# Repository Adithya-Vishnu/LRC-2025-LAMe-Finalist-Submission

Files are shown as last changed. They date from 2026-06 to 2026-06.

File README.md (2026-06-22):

# LRC-2025-LAMe-Finalist-Submission
Multi-robot coordination system developed for the Lam Research Challenge 2025, featuring an autonomous line follower (ALFR), a mecanum-based robotic manipulator (SARM), arena automation, and parametric CAD design.

# LAMe Multi-Robot Coordination System

### Lam Research Challenge 2025 | Top 24 Finalist Team

A cooperative multi-robot system developed for the **Lam Research Challenge 2025 (LRC)** by **Team LAMe**, comprising an autonomous line-following robot (**ALFR**) and a manually operated robotic manipulator (**SARM**) working together to complete a dynamic obstacle-clearing and navigation challenge.

Our team advanced from a pool of **7000+ applicants** to become one of the **Top 24 teams nationally**, qualifying for the final round held in Bangalore.

---

## Team LAMe

* Adithya Vishnu
* Harsh Chandwani
* Sreeja Srinivasan
* Sparsh Pradeep Jain

---

## Project Overview

The challenge required the development of two robots capable of coordinated task execution:

### ALFR (Advanced Line Follower Robot)

An autonomous robot responsible for:

* Following a predefined arena path
* Detecting and responding to obstacles
* Triggering arena events through gate interactions
* Completing navigation tasks within strict timing constraints

### SARM (Single Arm Moving Robot)

A mecanum-wheel-based robotic manipulator responsible for:

* Omnidirectional movement
* Identifying and removing obstacles
* Pick-and-place operations
* Clearing the path for ALFR navigation

The robots operate together, with SARM removing obstacles while ALFR autonomously continues task execution once the route is cleared.

---

## Key Features

### Autonomous Navigation

* PID-based line following
* Multi-sensor line detection
* Obstacle-aware navigation
* Recovery logic for line loss
* Real-time path correction

### Robotic Manipulation

* Mobile robotic arm platform
* Mecanum wheel omnidirectional drive
* Object grasping and relocation
* Pick-and-place workflow
* Manual control interface

### Arena Automation

* Gate-triggered events
* Relay-based control systems
* Automated LED activation
* Fluid delivery sequence integration
* Event-driven challenge execution

### Mechanical Design

* Custom-designed ALFR chassis
* Custom SARM mechanical components
* Arena infrastructure design
* 3D-printed robot components
* Mechanical integration and assembly

### CAD Automation

* Fully parametric flange-bolt assembly
* Excel-linked SolidWorks design tables
* Equation-driven geometry generation
* Automated design regeneration
* Scalable assembly configuration

---

## Software Stack

### Simulation

* CoppeliaSim

### Programming

* Arduino
* C++
* Python

### CAD

* SolidWorks
* Fusion 360

### Electronics

* ESP32
* IR Sensor Arrays
* Ultrasonic Sensors
* Relay Modules
* Load Cells
* Peristaltic Pump Systems

---

## Competition Workflow

1. ALFR begins autonomous navigation.
2. Obstacles encountered on the route halt progression.
3. SARM identifies and removes obstacles.
4. ALFR resumes navigation.
5. Gate-based events trigger arena automation.
6. Fluid delivery and LED activation tasks are executed.
7. ALFR completes the course and reaches the final checkpoint.

---

## Results

* Qualified among **Top 96** from over **7000 applicants**
* Advanced to the **Top 24 Finalists Nationwide**
* Invited to compete at the **Lam Research Challenge Finals, Bangalore**
* Successfully completed both simulation and hardware evaluation rounds

---

## Repository Structure

```text
├── CAD/
├── CoppeliaSim/
├── Arduino/
├── Documentation/
├── Hardware/
├── Images/
├── Videos/
└── README.md
```

---

## Future Improvements

* ROS2 integration
* Autonomous obstacle removal
* Computer vision-based object detection
* SLAM-assisted navigation
* Multi-agent task planning
* Wireless telemetry dashboard

---

## Acknowledgements

We thank Lam Research, T-Works, IIT Kanpur, and the Robotics Club community for providing the opportunity, resources, and mentorship that made this project possible.

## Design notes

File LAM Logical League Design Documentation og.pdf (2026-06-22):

# LAM Research Challenge 2025

# Stage-1: Logical League

## Team LAMe: LRC-U-0517-1

## Members:

### Adithya Vishnu

### Harsh Chandwani

### Sreeja Srinivasan

### Sparsh Pradeep Jain

# Key challenges handled

- Obstacle Configuration

To evaluate the system’s obstacle detection and navigation capabilities, three distinct obstacles were strategically positioned within the arena to introduce varying levels of difficulty.

- Obstacle 1: Placed along a straight path, designed to test basic obstacle detection and removal efficiency.
- Obstacle 2: Located on a corner, introducing a moderate challenge due to limited maneuvering space.
- Obstacle 3: Positioned immediately after a turn, simulating a complex real-world obstruction scenario that required precise timing and coordination between the SRM and ALFR.

This configuration ensured a progressive difficulty setup, allowing systematic testing of both detection accuracy and response timing during obstacle clearance.

- Obstacle Interaction Logic

The obstacle interaction mechanism involved two coordinated systems — the Support Robot Module (SRM) and the Autonomous Line-Following Robot (ALFR).

- The SRM was responsible for picking up, and relocating obstacles away from the line path to maintain a clear route for the ALFR.
- The ALFR was programmed to stop automatically upon detecting an obstacle and resume navigation only after the SRM had successfully cleared it.

During testing, three different obstacle shapes — a cube, a cylinder, and a sphere — were used. The SRM’s gripper arm was able successfully lift each shape, demonstrating versatility and precision in obstacle handling.

- Time Limit

The arena challenge included a time-based performance metric, requiring the task to be completed within 10 minutes.

- In the baseline test (without obstacles), the ALFR successfully navigated the entire arena in 40 seconds, showcasing efficient line-following and path optimization.
- In the full test (with all obstacles present), the combined system of SRM and ALFR completed the entire course in 3 minutes, clearing each obstacle sequentially as encountered.

This performance demonstrated reliable coordination between the robots and efficient task execution well within the prescribed time limit.

- Peristaltic Pump Verification

We have used a load cell to measure the weight of water dispensed and all other components of the circuits will be tuned such that it triggers the switch at the exact weight required.

# Circuit Diagram:

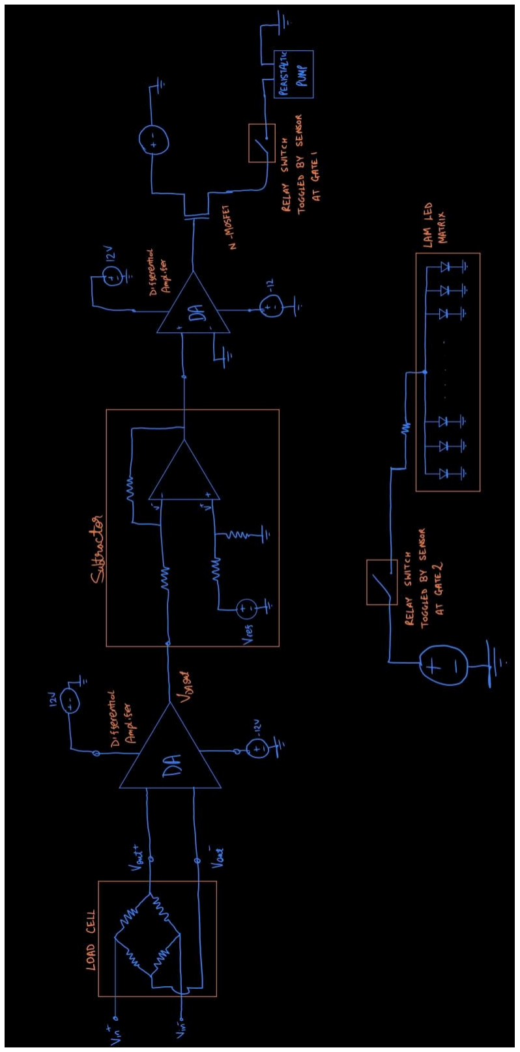
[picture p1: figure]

## Detailed Explanation:

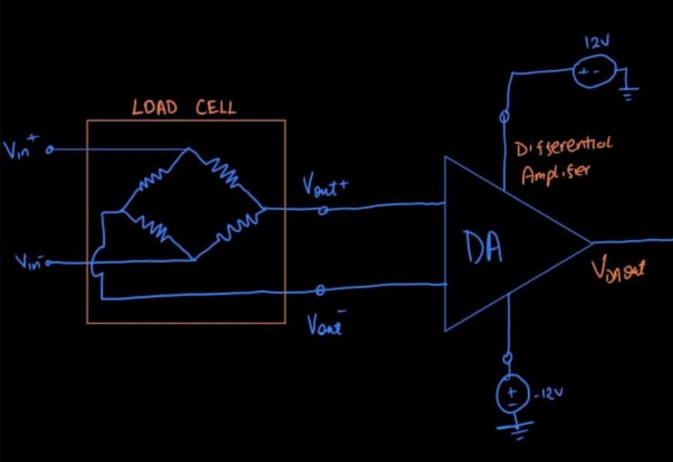
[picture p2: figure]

A load cell is a transducer that converts mechanical force (weight or load) into an electrical signal. It operates based on the strain gauge principle, where a change in force causes a corresponding change in electrical resistance.

When weight is applied to the load cell, the metal body (elastic element) deforms slightly. This deformation alters the resistance of the strain gauges attached to it, which are connected in a Wheatstone bridge configuration. The resulting output is a small differential voltage proportional to the applied load.

Since this voltage is typically in the millivolt range (mV), it must be amplified using an instrumentation amplifier such as the HX711 module.

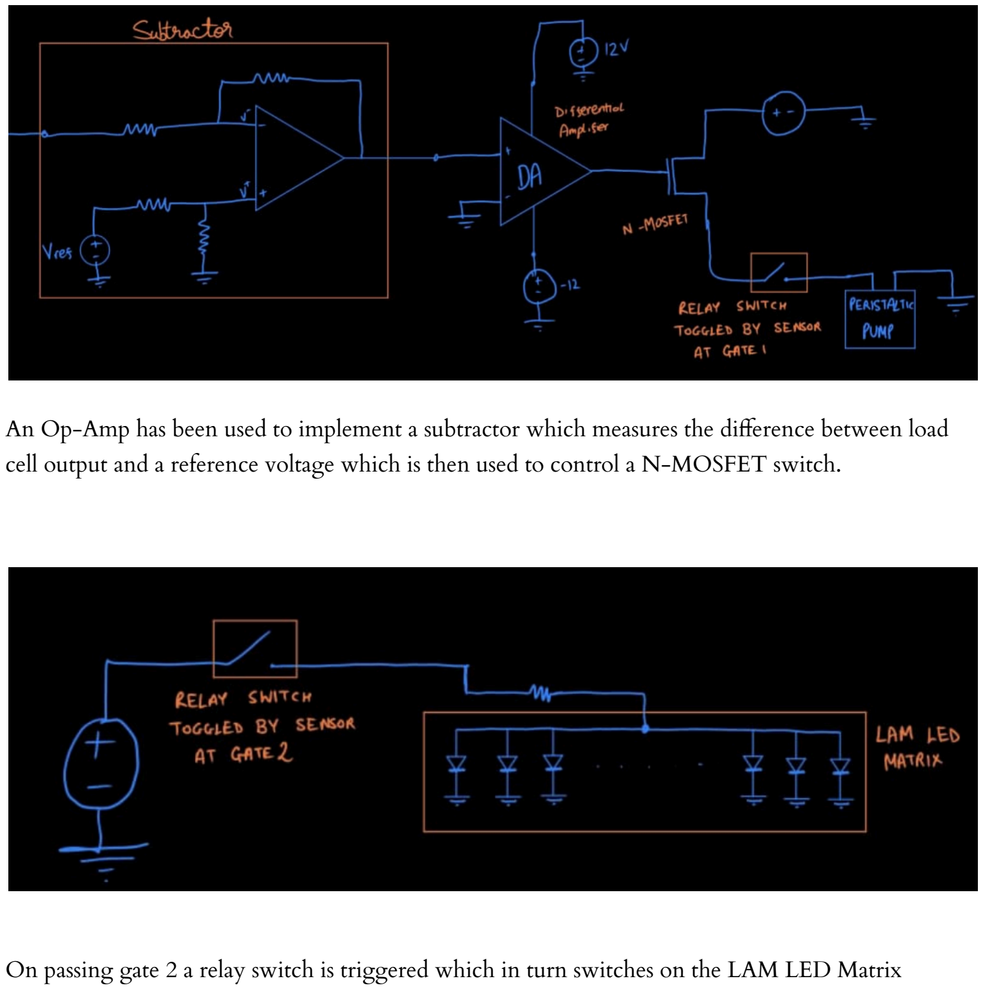
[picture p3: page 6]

An Op-Amp has been used to implement a subtractor which measures the difference between load cell output and a reference voltage which is then used to control a N-MOSFET switch.

On passing gate 2 a relay switch is triggered which in turn switches on the LAM LED Matrix

# Key features of custom code for line following of ALFR:

### 1. Error Calculation with 5 IR sensors:

The five IR sensors return intensity values (black < 0.5).
Each sensor is assigned a weight (−4000 to +4000) based on its position.
The error is the weighted average of all active (black-detecting) sensors:

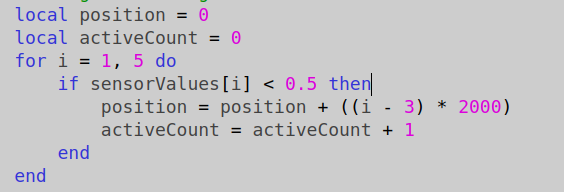
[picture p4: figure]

### 2. PID Control:

Computes proportional, integral, and derivative terms of the error to correct steering smoothly. The PID parameters were carefully tuned to achieve maximum speed and accuracy in line tracking.

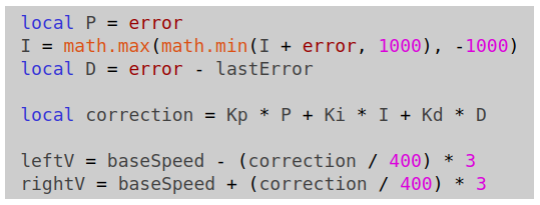
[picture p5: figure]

### 3. Obstacle Handling:

Stops the robot when the proximity sensor detects an obstacle.

### 4. Line Recovery:

If all sensors lose the line, the robot turns in the direction of the last known error until the line is found again.

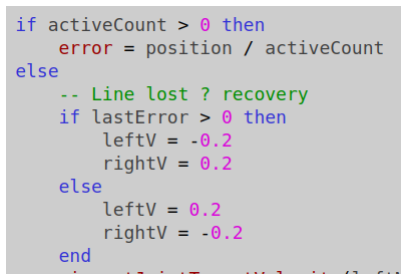
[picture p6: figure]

Key features of custom code for manual control of Single Arm Robot:

### 1. Custom Graphical UI:

Creates an on-screen control panel using simUI.create() with buttons for forward, backward, left, right, rotation, stop, and pick operations.

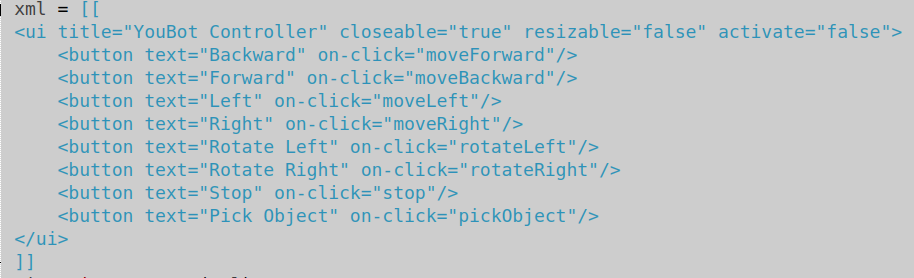
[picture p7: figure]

### 2. Mecanum Wheel Drive System:

Uses mecanum wheels to achieve omnidirectional movement, allowing the robot to move forward, backward, sideways, and rotate in place.

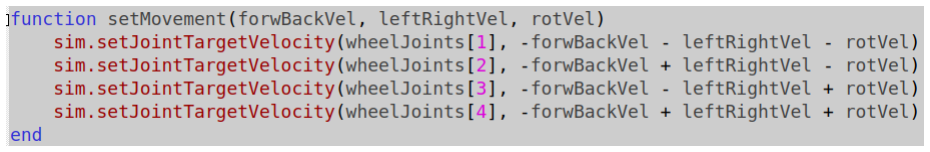
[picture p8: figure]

### 3. Arm and Gripper Control:

Functions to position the robotic arm and open/close the gripper using joint target positions.

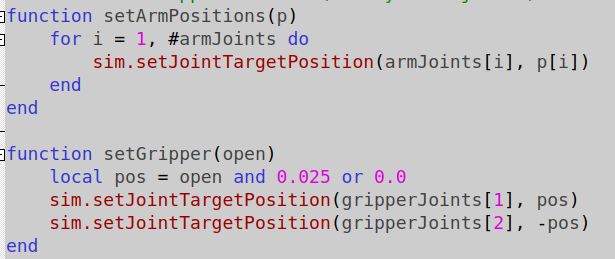
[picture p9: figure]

### 4. Pick-and-Place Operation:

Automated routine configured to pick an object: move to a ready pose, lower arm, close gripper, attach object, and lift it.

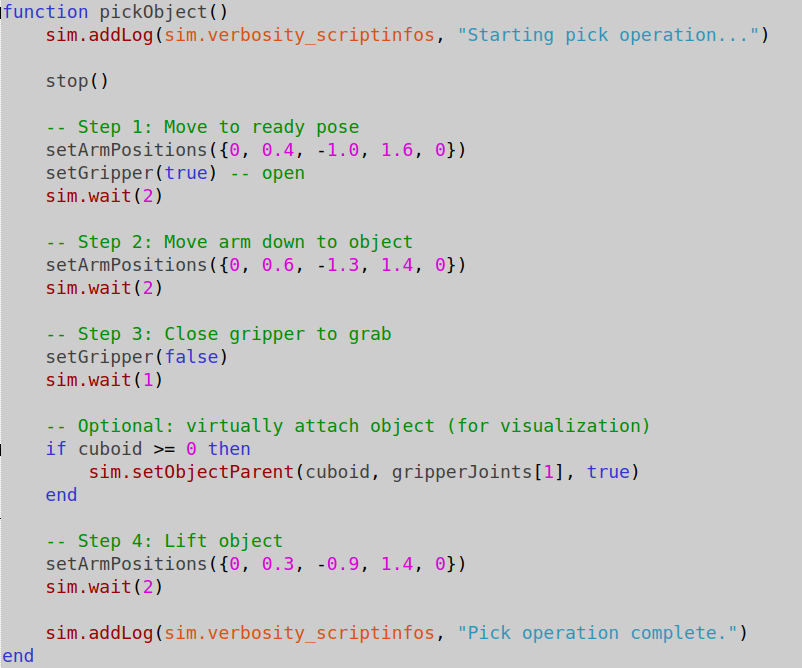
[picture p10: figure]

## Key features of code for LAM LED turning on when ALFR passes through gate 2:

### 1. LED color control

Turns LEDs red when activated, and black otherwise.

### 2. Persistent state flag

Keeps LEDs on once triggered, even after the object moves away.

# CUSTOM MODELS

## ALFR:

## So coming to the model of Automatic

Line follower Robot,

## we chose to go with this design because it has rotational symmetry, less moment of inertia to reduce

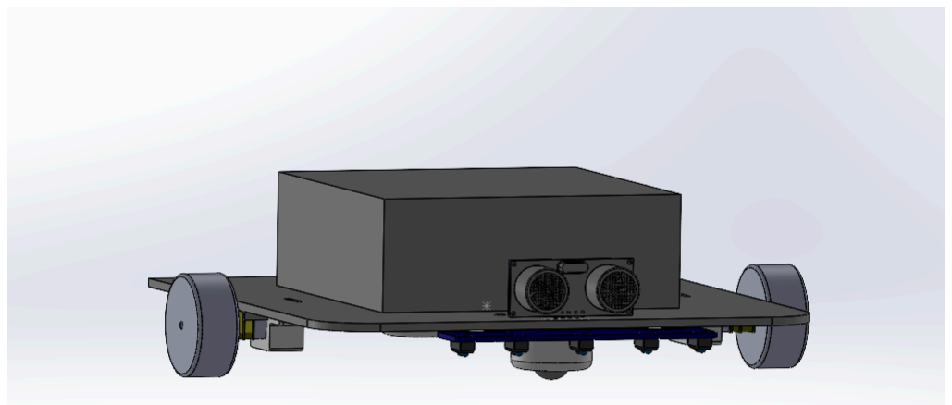
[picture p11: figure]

## chances of overshooting, which is really important for most efficient path following and preventing repetitive errors. And to remove any chance of rotation asymmetry we have provided two caster wheels at the front and

the back, to remove any chance of uneven torque distribution.

## Other than that we have made the design such that there is no chance of toppling and the mass is centred since the battery and other electronic

components are kept at the centre.

## SINGLE ARM - ROBOT

So the bot consists of multiple links. It starts from a stationary base that is attached to the mechanum wheel base. Then the rotating body is attached onto this stationary base through a servo and ball bearing for additional support. Now the first extension and second extension are designed to be of minimal weight and have enough supports (additional triangulations have been provided for this purpose to reduce the material used.)

### Now coming to the gripper, we have made the gripper such that it is adjustable for

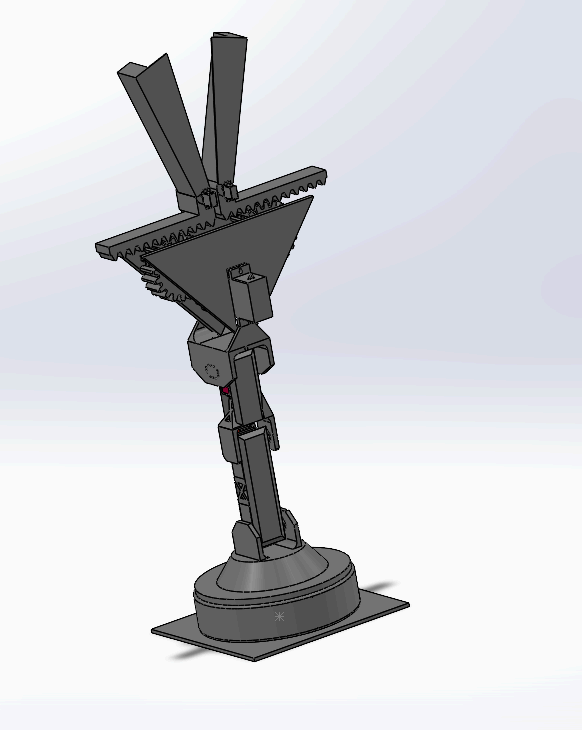
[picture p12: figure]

varying sizes and shapes of objects. This uses the principle of rack and pinion gears and a set of three intersecting spur gears to transfer the torque from one servo motor to both the set of racks equally thereby expanding the distance between the two arms. Then the design includes two additional servos on each

rack to better adjust the arms to fit regardless of what shape the object is of.

# PERISTALTIC PUMP

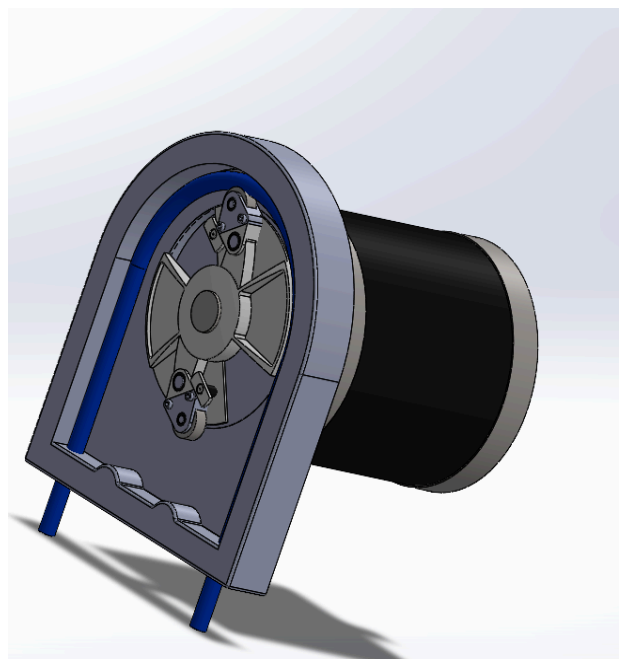
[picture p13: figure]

## Coming to the basic design of the peristaltic pump, We have used two rollers connected to a motor, that revolves the rollers periodically and controlled, which pushes specific volumes of fluid through the tube that can be controlled by controlling the number of rotations and changing

the thickness of the tube.

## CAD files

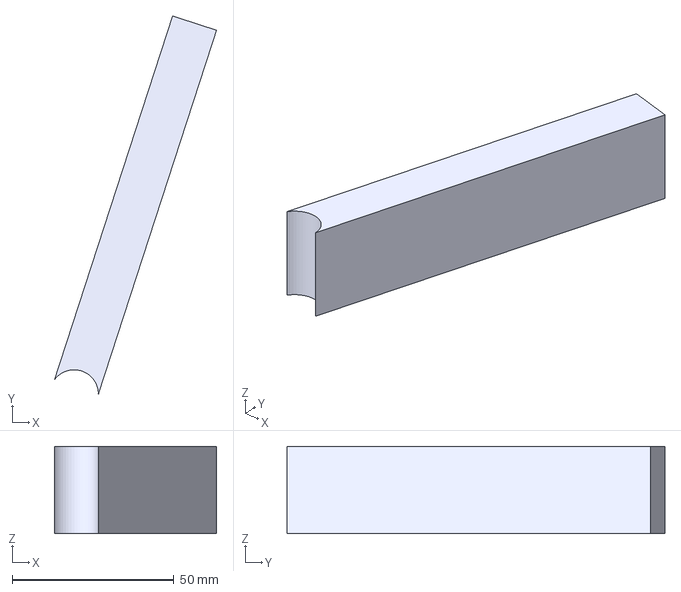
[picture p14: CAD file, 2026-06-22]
CAD/rack2_leg.step
50.0 x 116.7 x 27.0 mm

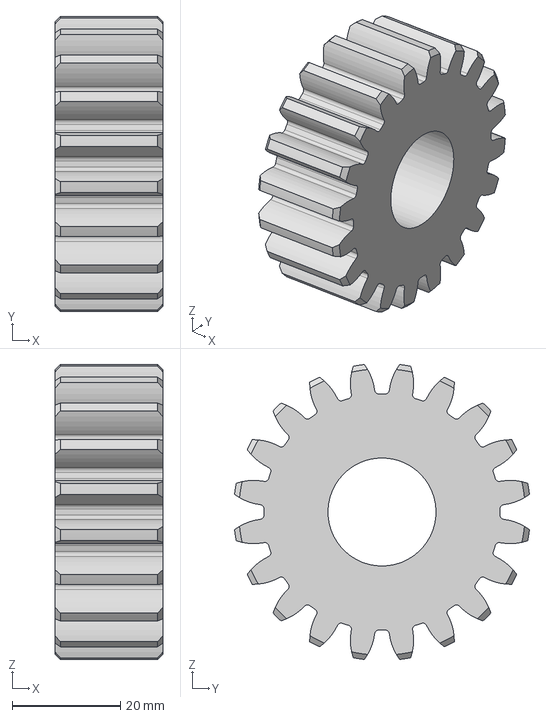
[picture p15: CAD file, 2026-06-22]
CAD/spur gear 20 teeth and 2.5mm module v1.step
20.0 x 54.6 x 54.6 mm

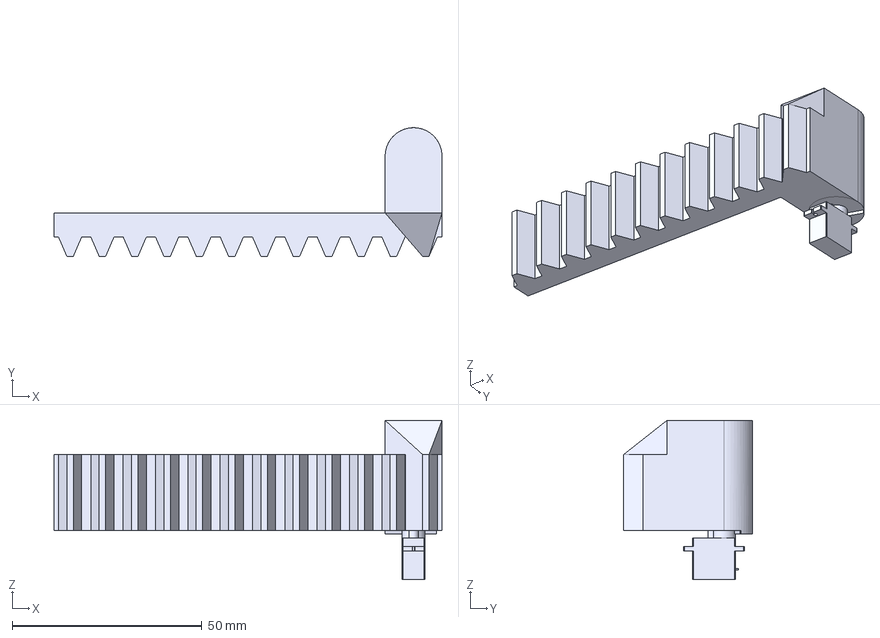
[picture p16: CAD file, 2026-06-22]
CAD/LEG1_BASE.step
102.3 x 33.9 x 42.0 mm

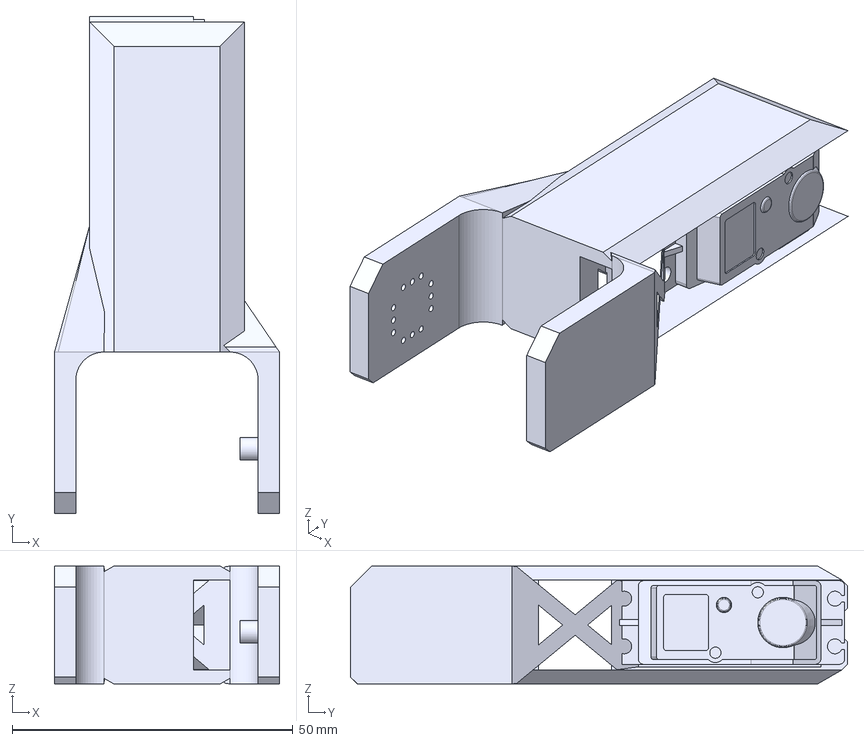
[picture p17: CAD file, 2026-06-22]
CAD/LEG2.step
40.1 x 88.5 x 21.0 mm

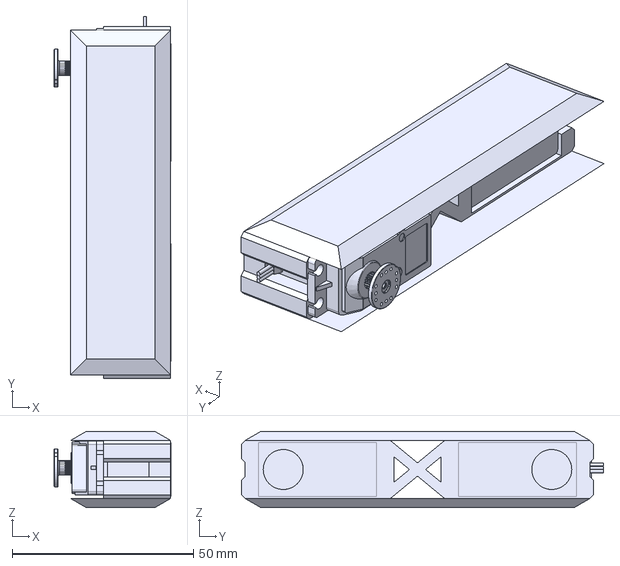
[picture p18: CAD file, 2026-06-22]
CAD/leg1.step
32.1 x 99.7 x 21.0 mm

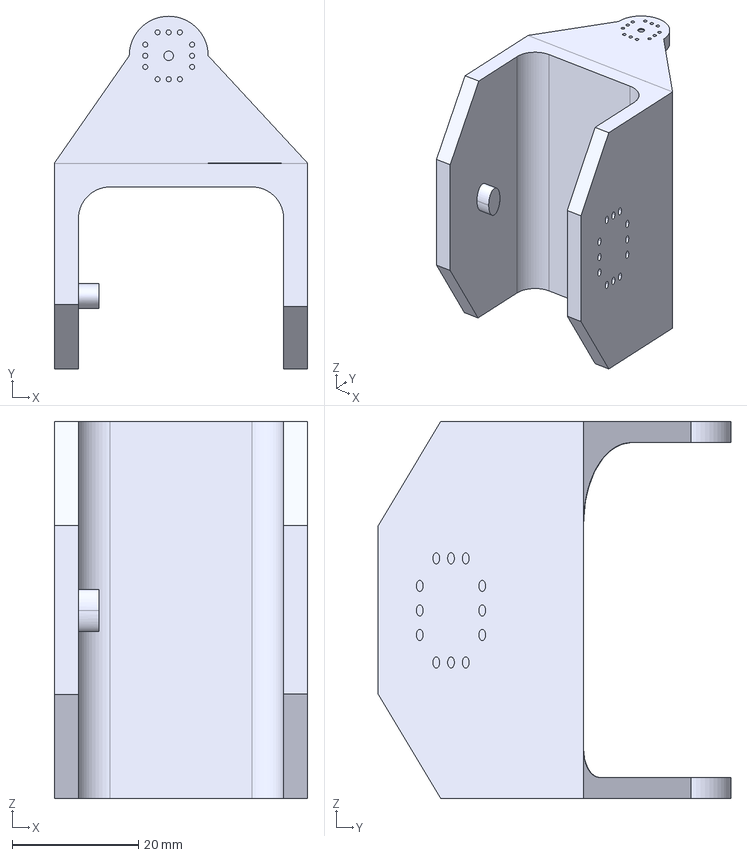
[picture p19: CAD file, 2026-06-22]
CAD/leg3.step
40.1 x 55.8 x 59.6 mm

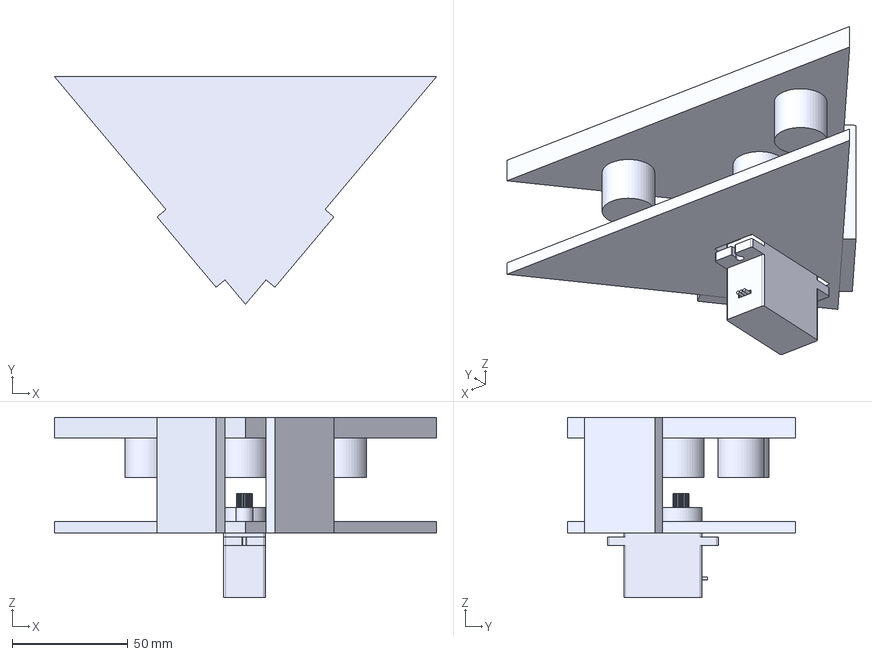
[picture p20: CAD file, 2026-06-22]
CAD/FINAL END.step
165.3 x 98.5 x 78.0 mm

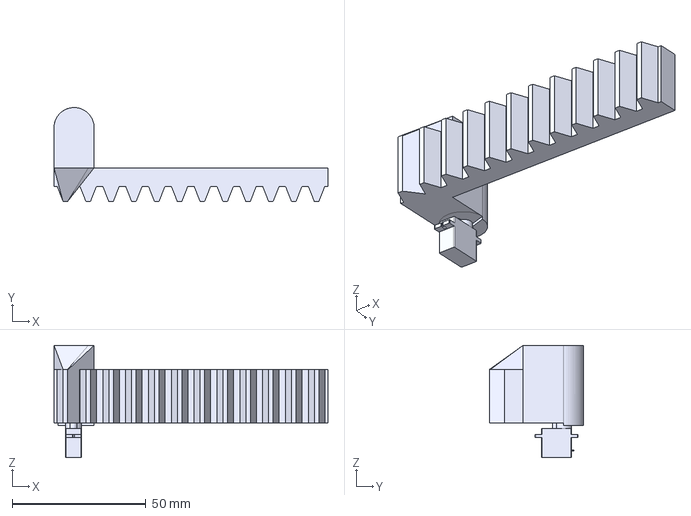
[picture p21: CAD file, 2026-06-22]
CAD/rack2_base.step
102.3 x 35.1 x 42.0 mm

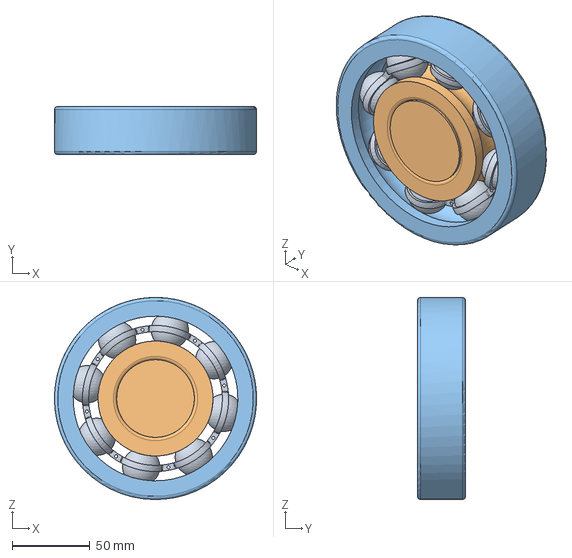
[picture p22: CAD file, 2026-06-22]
CAD/Ball_Bearing.step
130.0 x 31.0 x 130.0 mm

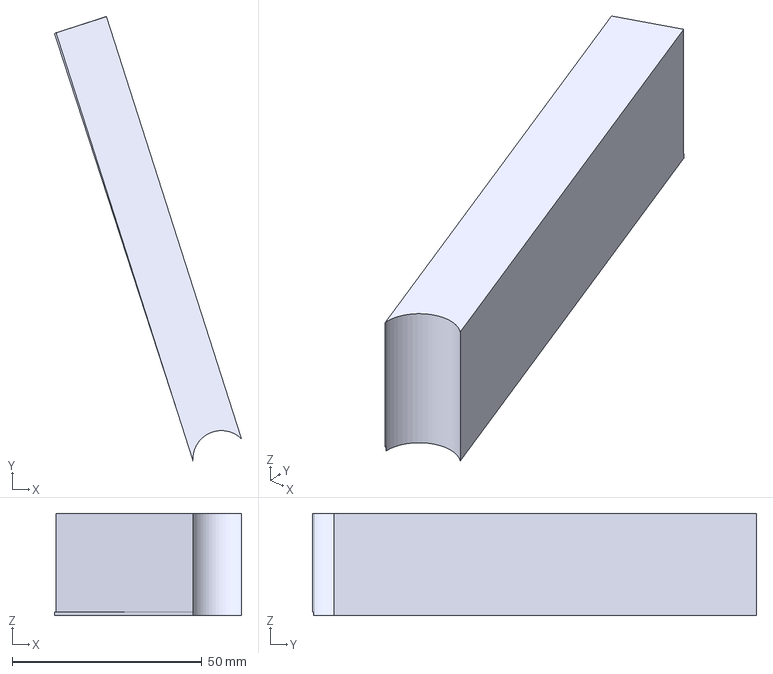
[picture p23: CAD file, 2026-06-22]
CAD/rack1_leg.step
49.3 x 117.0 x 27.0 mm

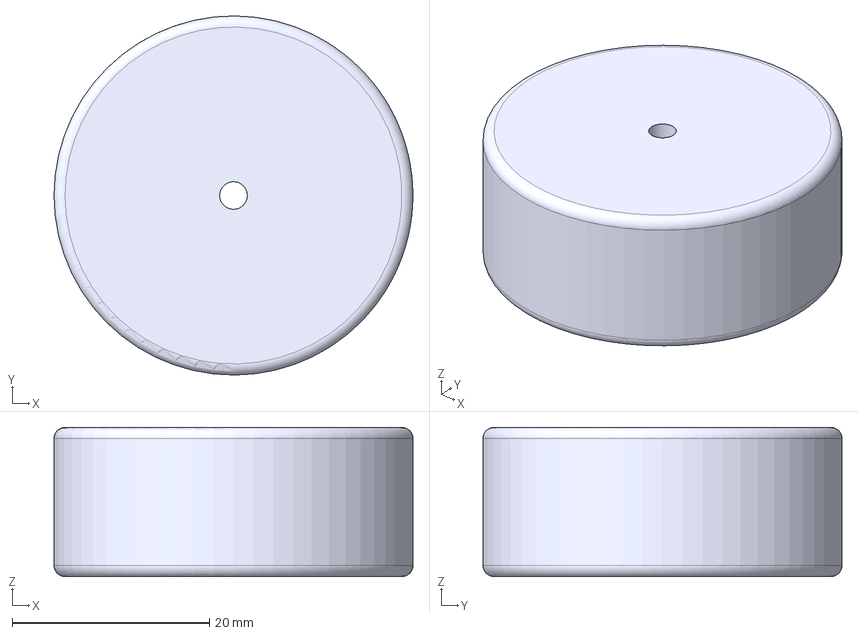
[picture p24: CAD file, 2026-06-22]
CAD/W1.step
36.4 x 36.4 x 15.1 mm

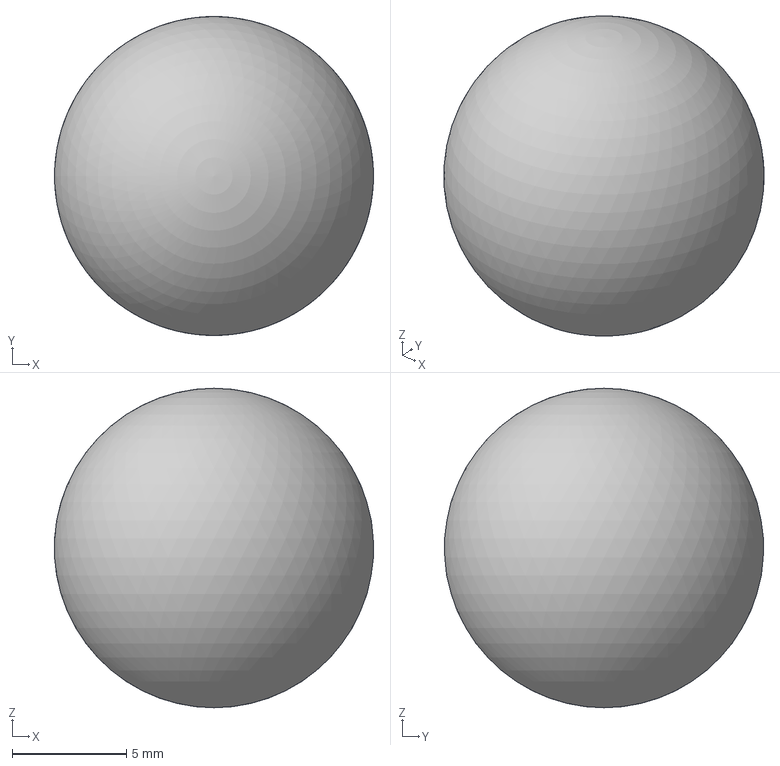
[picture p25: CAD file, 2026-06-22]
CAD/Sphere.step
14.0 x 14.0 x 14.0 mm

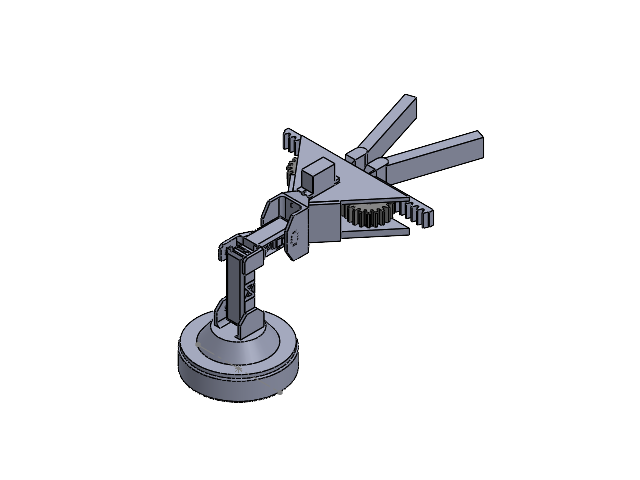
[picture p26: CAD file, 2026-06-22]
CAD/Assem13.SLDASM
Component.step
Ball_Bearing.step
leg1.step
LEG2.step
FINAL END.step
leg3
spur gear 20 teeth and 2.5mm module v1.step x 3
rack2_base.step
rack1_base.step
rack1_leg.step
rack2_leg.step

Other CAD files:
CAD/caster wheel_1_1.step.SLDASM
CAD/rack1_base.step
CAD/IR sensor array -5 sensors_1.step.SLDPRT
CAD/N20 Motor_2.step.SLDPRT
CAD/HC-SR04-UltrasonicSensor v7_1.step.SLDPRT
CAD/Component.iges
CAD/Component.step
CAD/Component9_1.step.SLDPRT
CAD/FINAL END.SLDPRT
CAD/base.step
CAD/leg3.SLDPRT

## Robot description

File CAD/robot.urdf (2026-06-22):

<?xml version="1.0"?>
<robot name="two_wheel_robot">
  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
  <link name="base_link">
    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
    <inertial>
      <mass value="5.0"/>
      <origin xyz="0 0 0" rpy="0 0 0"/>
      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
    </inertial>
  </link>

  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
  <link name="right_wheel">
    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
    <inertial>
      <mass value="1.0"/>
      <origin xyz="0 0 0" rpy="0 0 0"/>
      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
    </inertial>
  </link>

  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
  <link name="left_wheel">
    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
    <inertial>
      <mass value="1.0"/>
      <origin xyz="0 0 0" rpy="0 0 0"/>
      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
    </inertial>
  </link>

  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
  <link name="caster">
    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
    <inertial>
      <mass value="0.5"/>
      <origin xyz="0 0 0" rpy="0 0 0"/>
      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
    </inertial>
  </link>

  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
  <link name="imu_link">
    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
    <inertial>
      <mass value="0.1"/>
      <origin xyz="0 0 0" rpy="0 0 0"/>
      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
    </inertial>
  </link>

  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
  <link name="gps_link">
    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
    <inertial>
      <mass value="0.1"/>
      <origin xyz="0 0 0" rpy="0 0 0"/>
      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
    </inertial>
  </link>

  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
  <link name="lidar_link">
    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
    <inertial>
      <mass value="0.2"/>
      <origin xyz="0 0 0" rpy="0 0 0"/>
      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
    </inertial>
  </link>
  
  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
<link name="h_boom">
  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
  <inertial>
    <mass value="1.0"/>
    <origin xyz="0 0 0.25" rpy="0 0 0"/>
    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
  </inertial>
</link>

  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
  <link name="depth_camera_link">
    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
  </link>
  <link name="depth_camera_link_optical"></link>


  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
  <joint name="right_wheel_joint" type="continuous">
    <parent link="base_link"/>
    <child link="right_wheel"/>
    <origin xyz="0 -0.36 0" rpy="-1.5708 0 0"/>
    <axis xyz="0 0 1"/>
    <dynamics damping="0.1" friction="0.1"/>
  </joint>

  <joint name="left_wheel_joint" type="continuous">
    <parent link="base_link"/>
    <child link="left_wheel"/>
    <origin xyz="0 0.36 0" rpy="-1.5708 0 0"/>
    <axis xyz="0 0 1"/>
    <dynamics damping="0.1" friction="0.1"/>
  </joint>

  <joint name="caster_joint" type="fixed">
    <parent link="base_link"/>
    <child link="caster"/>
    <origin xyz="0.3 0 -0.09"/>
  </joint>

  <joint name="imu_joint" type="fixed">
    <parent link="base_link"/>
    <child link="imu_link"/>
    <origin xyz="0 0 0.075"/>
  </joint>

  <joint name="gps_joint" type="fixed">
    <parent link="base_link"/>
    <child link="gps_link"/>
    <origin xyz="-0.3 0 0.075"/>
  </joint>

  <joint name="lidar_joint" type="fixed">
    <parent link="base_link"/>
    <child link="lidar_link"/>
    <origin xyz="0.3 0 0.105"/>
  </joint>
  
  <joint name="h_boom_joint" type="fixed">
    <parent link="base_link"/>
    <child link="h_boom"/>
    <origin xyz="0 0 0.15" rpy="0 0 0"/> 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
  </joint>
  
  <joint name="depth_camera_joint" type="fixed">
    <parent link="h_boom"/>
    <child link="depth_camera_link"/>
    <origin xyz="0 0 0.25" rpy="0 0 0"/>
  </joint>

  <joint name="depth_camera_joint_optical" type="fixed">
    <origin xyz="0 0 0" rpy="-1.5708 0 -1.5708"/>
    <parent link="depth_camera_link"/>
    <child link="depth_camera_link_optical"/>
  </joint>



  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

</robot>

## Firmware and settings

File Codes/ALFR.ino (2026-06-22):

// ----------------- IR SENSOR ARRAY -----------------
const int sensorPins[6] = {A0, A1, A2, A3, A4, A5};   // Left → Right
int sensorValues[6];

// ----------------- MOTOR DRIVER (L298N) -----------------
#define ENA 5    // Left Motor PWM
#define IN1 6
#define IN2 7

#define IN3 8
#define IN4 9
#define ENB 10   // Right Motor PWM

// ----------------- ULTRASONIC SENSOR -----------------
#define TRIG 3
#define ECHO 4

// ----------------- PID PARAMETERS -----------------
float Kp = 0.04;
float Ki = 0.00;
float Kd = 0.01;

long error = 0, lastError = 0;
float P, I, D;

// ----------------- SPEED SETTINGS -----------------
int baseSpeed = 98;
int leftSpeed, rightSpeed;

// ==================================================
void setup() {

  Serial.begin(9600);

  // IR Sensor Pins
  for (int i = 0; i < 6; i++) {
    pinMode(sensorPins[i], INPUT);
  }
  pinMode(A6, INPUT_PULLUP);

  // Motor Pins
  pinMode(ENA, OUTPUT);
  pinMode(IN1, OUTPUT);
  pinMode(IN2, OUTPUT);
  pinMode(IN3, OUTPUT);
  pinMode(IN4, OUTPUT);
  pinMode(ENB, OUTPUT);

  // Ultrasonic Pins
  pinMode(TRIG, OUTPUT);
  pinMode(ECHO, INPUT);

  Serial.println("Line Follower with Obstacle Avoidance Ready...");
}

// ==================================================
// Ultrasonic Distance Function
long getDistance() {
  digitalWrite(TRIG, LOW);
  delayMicroseconds(2);

  digitalWrite(TRIG, HIGH);
  delayMicroseconds(10);
  digitalWrite(TRIG, LOW);

  long duration = pulseIn(ECHO, HIGH, 30000); // timeout 30ms
  long distance = duration * 0.034 / 2;       // convert to cm

  return distance;
}

// ==================================================
void loop() {
  // // -------- ULTRASONIC SAFETY STOP --------
  long distance = getDistance();
  if (distance > 0 && distance < 15) {
    motor_stop();
    motor_drive(-10, 10); 
    Serial.print("Obstacle detected: ");
    Serial.print(distance);
    Serial.println(" cm | Stopping...");
    delay(1000);
    return;
  }

  long position = 0;
  int activeCount = 0;

  // // -------- READ 8 IR SENSORS WITH WEIGHTS --------
  for (int i = 0; i < 6; i++) sensorValues[i] = digitalRead(sensorPins[i]);
  for (int i = 0; i < 6; i++) {
    if (sensorValues[i] == 1) {  // 0 = BLACK line
      long weight = (i * 2000 - 5000);  // -7000 to +7000
      position += weight;
      if(i==0||i==6)position += weight;
      activeCount++;
      //Serial.print(i);
    }
  }
   //Serial.println(".");
   //delay(2000);

  // -------- IF LINE LOST, RECOVER --------
  if (activeCount == 0) {
    if (lastError > 0)
      motor_drive(-80, 80);   // turn right
    else
      motor_drive(80, -80);   // turn left

    Serial.println("Line lost! Recovering...");
    return;
  }

  // // -------- CALCULATE ERROR --------
  error = position / activeCount;

  // // -------- PID CONTROL --------
   P = error;
   I += error;
   I = constrain(I, -1000, 1000);
   D = error - lastError;

  float correction = Kp * P + Ki * I + Kd * D;

  leftSpeed  = baseSpeed - correction;
  rightSpeed = baseSpeed + correction;

  leftSpeed  = constrain(leftSpeed,  -255, 255);
  rightSpeed = constrain(rightSpeed, -255, 255);


 //-------- DRIVE MOTORS --------
  motor_drive(leftSpeed, rightSpeed);

  lastError = error;


}

// ==================================================
// MOTOR CONTROL FOR L298N
void motor_drive(int left, int right) {

  // LEFT MOTOR
  if (left >= 0) {
    analogWrite(ENA, left);
    digitalWrite(IN1, HIGH);
    digitalWrite(IN2, LOW);
  } else {
    analogWrite(ENA, -left);
    digitalWrite(IN1, LOW);
    digitalWrite(IN2, HIGH);
  }

  // RIGHT MOTOR
  if (right >= 0) {
    analogWrite(ENB, right);
    digitalWrite(IN3, HIGH);
    digitalWrite(IN4, LOW);
  } else {
    analogWrite(ENB, -right);
    digitalWrite(IN3, LOW);
    digitalWrite(IN4, HIGH);
  }
}

// ==================================================
void motor_stop() {
  analogWrite(ENA, 0);
  digitalWrite(IN1, LOW);
  digitalWrite(IN2, LOW);

  analogWrite(ENB, 0);
  digitalWrite(IN3, LOW);
  digitalWrite(IN4, LOW);
}

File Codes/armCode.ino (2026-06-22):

#define CUSTOM_SETTINGS
#define INCLUDE_GAMEPAD_MODULE

#include <Arduino.h>
#include <DabbleESP32.h>
#include <ESP32Servo.h>

// ===== SERVOS =====
Servo baseServo;
Servo shoulderServo;
Servo elbowServo;
Servo wristPitchServo;
Servo gripperServo;

// ===== PIN ASSIGNMENTS =====
#define BASE_PIN 13
#define SHOULDER_PIN 12
#define ELBOW_PIN 14
#define WRIST_PIN 27
#define GRIP_PIN 26

// Current servo angles
int baseAngle = 90;
int shoulderAngle = 90;
int elbowAngle = 90;
int wristAngle = 90;
int gripperAngle = 20;   // open

// Current selected servo
// 0 = Base, 1 = Shoulder, 2 = Elbow, 3 = Wrist, 4 = Gripper
int selectedServo = 0;

void setup() {
  Serial.begin(115200);

  // Start Dabble Bluetooth
  Dabble.begin("ESP32_ARM");

  // Attach servos to pins
  baseServo.attach(BASE_PIN);
  shoulderServo.attach(SHOULDER_PIN);
  elbowServo.attach(ELBOW_PIN);
  wristPitchServo.attach(WRIST_PIN);
  gripperServo.attach(GRIP_PIN);

  Serial.println("Robotic Arm Ready! Open Dabble → Gamepad → Connect.");
}

void loop() {
  Dabble.processInput();

  // ---------- SELECT SERVO ----------
  // if (GamePad.isSquarePressed())  selectedServo = 0; // Base
  if (GamePad.isSquarePressed()) selectedServo = 1; // Shoulder
  if (GamePad.isTrianglePressed())   selectedServo = 2; // Elbow
  if (GamePad.isCirclePressed())    selectedServo = 3; // Wrist
  if (GamePad.isCrossPressed())       selectedServo = 4; // Gripper

  // ---------- MOVE SELECTED SERVO ----------
  int moveAmount = 2; // degrees per press

  if (selectedServo == 0) {
    // Base controlled by LEFT/RIGHT
    if (GamePad.isRightPressed()) baseAngle += moveAmount;
    if (GamePad.isLeftPressed())  baseAngle -= moveAmount;
    baseAngle = constrain(baseAngle, 0, 180);
    baseServo.write(baseAngle);
  } 
  else {
    switch(selectedServo) {
      // case 0: // Base
      //   if (GamePad.isUpPressed()) baseAngle += moveAmount;
      //   if (GamePad.isDownPressed()) baseAngle -= moveAmount;
      //   baseAngle = constrain(baseAngle, 0, 180);
      //   baseServo.write(baseAngle);
      //   break;
      case 1: // Shoulder
        if (GamePad.isUpPressed()) shoulderAngle += moveAmount;
        if (GamePad.isDownPressed()) shoulderAngle -= moveAmount;
        shoulderAngle = constrain(shoulderAngle, 0, 180);
        shoulderServo.write(shoulderAngle);
        break;

      case 2: // Elbow
        if (GamePad.isUpPressed()) elbowAngle += moveAmount;
        if (GamePad.isDownPressed()) elbowAngle -= moveAmount;
        elbowAngle = constrain(elbowAngle, 0, 180);
        elbowServo.write(elbowAngle);
        break;

      case 3: // Wrist
        if (GamePad.isUpPressed()) wristAngle += moveAmount;
        if (GamePad.isDownPressed()) wristAngle -= moveAmount;
        wristAngle = constrain(wristAngle, 0, 180);
        wristPitchServo.write(wristAngle);
        break;

      case 4: // Gripper
        if (GamePad.isUpPressed()) gripperAngle += moveAmount;
        if (GamePad.isDownPressed()) gripperAngle -= moveAmount;
        gripperAngle = constrain(gripperAngle, 0, 180);
        gripperServo.write(gripperAngle);
        break;
    }
  }

  delay(20); // smooth update
}
